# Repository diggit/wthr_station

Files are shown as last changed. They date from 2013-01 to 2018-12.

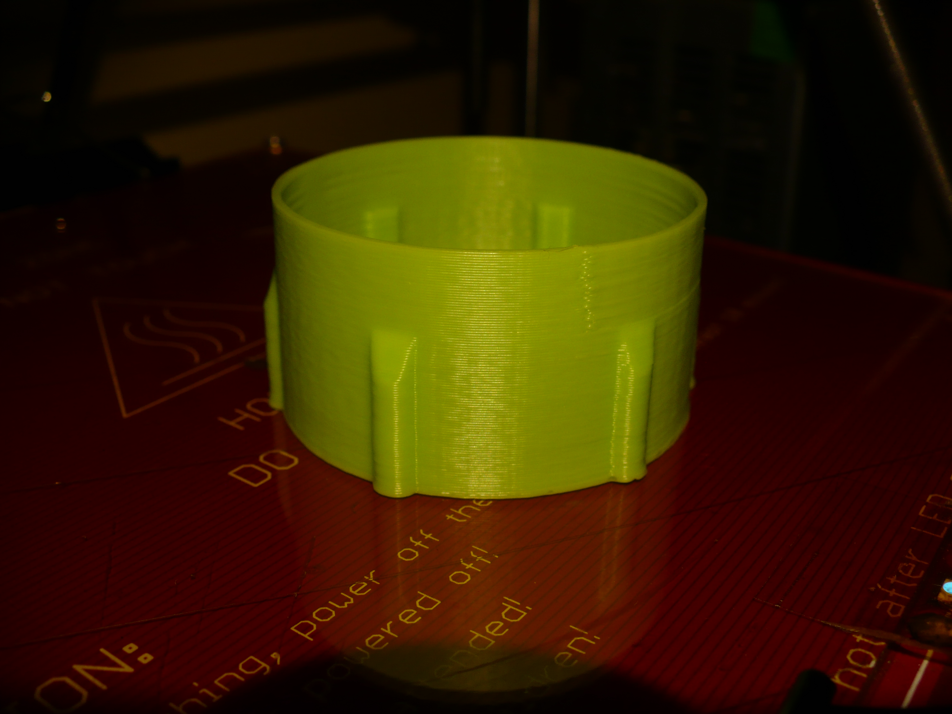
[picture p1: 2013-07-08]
web_app/photo/img3.jpg

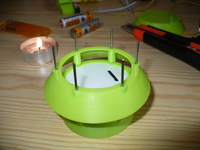
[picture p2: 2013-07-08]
web_app/photo/thumb/img4.jpg

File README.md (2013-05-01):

#Weather station#
============

Final project on secondary school, meteorological/weather station with web access.

## Divided into two main parts:
* Sensors with MCU outside, collecting various values. Newly extended by temperature sensor board (3 ICs). 
* Software running on RaspberryPi, grabs values from sensor "module",
    stores them in mysql database and publishes them on web.

## Material here :

* In **multi_sens** directory are complete sources for sensor module with libraries
  can be build with avr-gcc (tested on (arch)linux with 4.8.0).

* In **root** is python script. Periodicaly executed by cron (every 1O mins and 1min). After execution sends request to sensor
  module (serial communication). Returned structured string is decoded into mesured values. Then script stores values
  into mysql database for further usage and requests some last values. From returned values is generated javascript file
  containing array fileled with values. (used by web page)
  Data from minute updates are used for webpage header only. The are not stored for further usage.

* In **web_app** is web application's root, so index.html and value file(s) generated by script described above are here.
  Design itself is not cool or awesome but works as it should.

* In **electonics** are schematics, PSB designs, their exports for printing, etc.

* In **designs** are models of housing for sensor module now, openscad source and stls of individual parts.
  STLs may be out of date. Use openscad to get up to date design of housing.

* In **photo** are photos of station and it's parts. It really exists!

## STATUS
* working, needs webpage design improvement
* look at: http://m72.dkm.cz or http://meteo-chodov.tk
* ~~Temperature measurements from BMP085 are quite accurate.~~ Sometimes happen, that sensor returs 0°C instead of real value. I was unable to fix it up.
* Extension board with 3 temperature sensors ADT7410 16bit i2c ICs is working. BMP085 reports higher temperature, 1.5°C (approx) above new sensor's value. 
* my 3D printer is not functional now, but I prepared top housing part for new light sensor. This sensor is in queue.

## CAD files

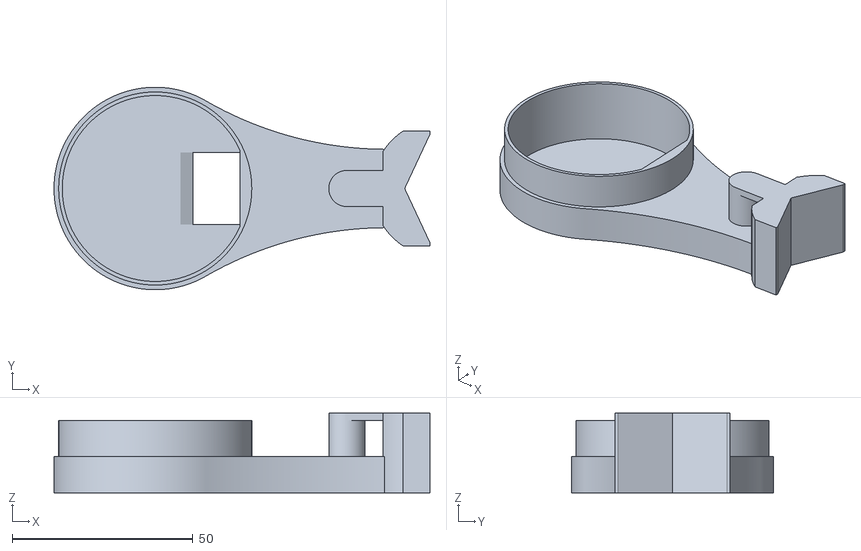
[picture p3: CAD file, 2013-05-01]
designs/sensor_module_housing_rodmount.stl
104.0 x 56.0 x 22.0

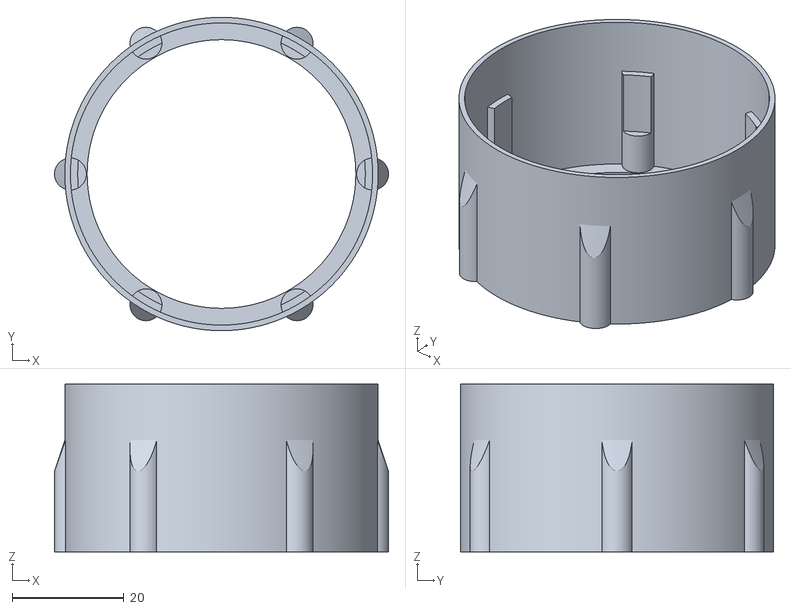
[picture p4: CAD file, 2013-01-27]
designs/sensor_module_housing_bottom.stl
59.7 x 56.0 x 30.0

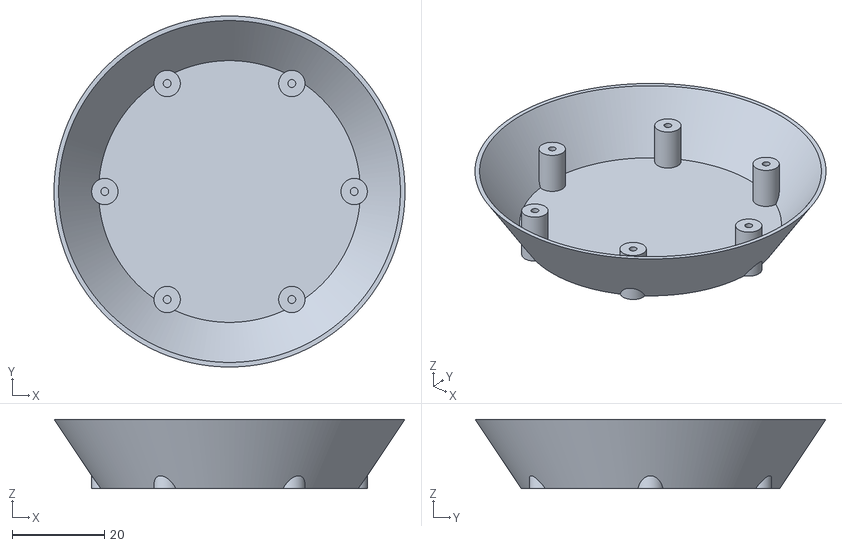
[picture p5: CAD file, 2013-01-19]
designs/sensor_module_housing_top.stl
76.0 x 76.0 x 15.0

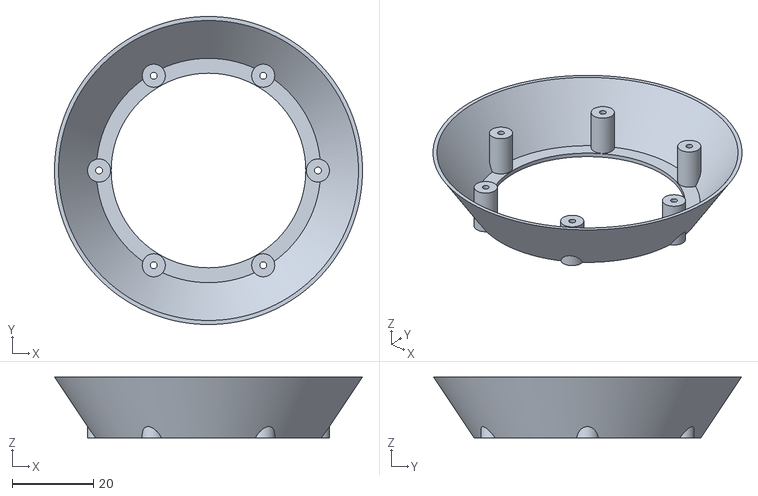
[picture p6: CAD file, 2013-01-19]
designs/sensor_module_housing_middle.stl
76.0 x 76.0 x 15.0

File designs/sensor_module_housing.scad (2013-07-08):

//$fn=200;
$fa=0.5;
$fs=0.1;
T_dia_in=54;
T_thickness=1;
T_height=30;

R_dia_in=T_dia_in;
R_thickness=1;
R_dia_increase=10;
R_height=15;
R_count=3;
R_overlap=4;
R_base=4;

C_count=6;
C_dia_in=1.7;
C_thickness=2;

render=0; //1 bottom, 2 middle (1 floor), 3 top, 4 rod mount,5 top W/ window, 0 all

E_dia=51.4;
E_height=8.5;

M_in_height=10;
M_in_thickness=1;
M_gap=0.3;
M_height=10;
M_cutoff_dia=200;
M_cutoff_angle=30;

if(render==1){
	rotate(a=[180,0,0]){base();}
}
else if(render==2){
	rotate(a=[180,0,0]){rings(1,0);}
}
else if(render==3){
	rotate(a=[180,0,0]){
		rings(1,0);
		top_plate(R_height-1.5);
	}
}
else if(render==4)
{
	rod_mount(10);
}
else if(render==5)
{
	rotate(a=[180,0,0]){
	rings(1,0);
	difference(){
		top_plate(R_height-1.5);
		translate([-5,-5,10])cube([10,10,10]);
		//translate([-10,-10,R_height-0.6])cube([20,20,1]);
		}
	translate([9,-5,R_height-3-1.5])
		difference(){
			cylinder(r=3,h=3);
			cylinder(r=1.3,h=3);
		}
	translate([9,5,R_height-3-1.5])
		difference(){
			cylinder(r=3,h=3);
			cylinder(r=1.3,h=3);
		}
	
		
	}
	
}
else {
	rings(R_count,T_height-R_overlap);
	top_plate(T_height+R_count*(R_height-R_overlap)-1,0);
	base();
	rod_mount(0);
}




module base(){
	difference(){
		union(){
			difference(){//main tubeBH1750FVI
					cylinder(r=T_dia_in/2+T_thickness,h=T_height);
					cylinder(r=T_dia_in/2,h=T_height);
			}

			difference()
			{
				for(i=[0:1:C_count-1]){//columns
					rotate(a=[0,0,i*(360/C_count)]){
						translate(v=[T_dia_in/2,0,10]){
								cylinder(r=C_dia_in/2+C_thickness,h=T_height-10);
						}
					}
				}
				translate(v=[0,0,T_height-15-E_height]){
					cylinder(r=E_dia/2,h=15);
				}
				translate(v=[0,0,10])
				{
					difference(){
						cylinder(h=15,r=T_dia_in/2+T_thickness+5);
						cylinder(h=15,r1=T_dia_in/2+T_thickness,r2=T_dia_in/2+T_thickness+5);
					}
				}
			}
			
			
			translate(v=[0,0,T_height-1]){//ring for safe printing
				difference(){
					cylinder(h=1,r=T_dia_in/2+R_thickness);
					cylinder(h=1,r=T_dia_in/2+R_thickness-R_base);
				}
			}
		}
		for(i=[0:1:C_count-1]){
			rotate(a=[0,0,i*(360/C_count)]){
				translate(v=[T_dia_in/2,0,T_height-10+1]){
						cylinder(r=C_dia_in/2,h=R_height);
				}
			}
		}
		
	}
}


module rings(count,height_offset){
	translate(v=[0,0,height_offset]){
		for(i=[0:1:count-1]){
			translate(v=[0,0,(R_height-R_overlap)*i]){
				difference(){
					union(){//union of ring and columns
						difference(){
							cylinder(h=R_height,r2=R_dia_in/2+R_thickness,r1=R_dia_increase+R_dia_in/2+R_thickness);
							cylinder(h=R_height,r2=R_dia_in/2,r1=R_dia_increase+R_dia_in/2);
						}
						translate(v=[0,0,R_height-1]){//ring for safe printing
							difference(){
								cylinder(h=1,r=R_dia_in/2+R_thickness);
								cylinder(h=1,r=R_dia_in/2+R_thickness-R_base);
							}
						}
						for(i=[0:1:C_count-1]){//columns
							rotate(a=[0,0,i*(360/C_count)]){
								translate(v=[T_dia_in/2,0,R_overlap]){
										cylinder(r=C_dia_in/2+C_thickness,h=R_height-R_overlap);
								}
							}
						}
					}//cut holes in columns
					for(i=[0:1:C_count-1]){
						rotate(a=[0,0,i*(360/C_count)]){
							translate(v=[T_dia_in/2,0,R_overlap]){
									cylinder(r=C_dia_in/2,h=R_height-R_overlap);
							}
						}
					}
				}
			}
		}
	}
}

module top_plate(height_offset){
	translate(v=[0,0,height_offset]){
		cylinder(h=1.5,r2=R_dia_in/2+R_thickness,r1=R_dia_in/2+2*R_thickness);
		for(i=[0:1:C_count-1]){//columns
			rotate(a=[0,0,i*(360/C_count)]){
				translate(v=[T_dia_in/2,0,0]){
						cylinder(r=C_dia_in/2+C_thickness,h=1.5);
				}
			}
		}
	}
}

module rod_mount(height_offset)
{
	color("aqua"){
		translate(v=[0,0,height_offset])
		{
			difference()
			{
				cylinder(h=M_in_height,r=T_dia_in/2-M_gap);
				cylinder(h=M_in_height+1,r=T_dia_in/2-M_gap-M_in_thickness);
			}
			difference()
			{
				translate(v=[0,0,-10])
				{
					difference()
					{
						cylinder(h=M_height,r=T_dia_in/2+T_thickness);
						translate(v=[0,0,2]){cylinder(h=M_height-2,r=T_dia_in/2-M_gap-M_in_thickness);}
					}
					difference()
					{
						translate(v=[0,-T_dia_in/2,0]){cube([cos(90-M_cutoff_angle)*(T_dia_in/2+T_thickness+M_cutoff_dia/2),T_dia_in,M_height]);}
						for(i=[0,1])
						mirror([0,i,0])
						{	
							rotate([0,0,-M_cutoff_angle])
							{
								translate(v=[-20,0,0]){cube([20,70,M_height]);}
								translate(v=[0,T_dia_in/2+T_thickness+M_cutoff_dia/2,0])
								{
								
									cylinder(h=M_height,r=M_cutoff_dia/2);
								
								}
							}
						}
						cylinder(h=M_in_height+1,r=T_dia_in/2-M_gap-M_in_thickness);
						//translate(v=[cos(90-M_cutoff_angle)*(T_dia_in/2+T_thickness+M_cutoff_dia/2),-T_dia_in/2,0])
						//{//the end of mount
						//	cube([100,T_dia_in,M_height]);
							
						//}
					}
					translate(v=[cos(90-M_cutoff_angle)*(T_dia_in/2+T_thickness+M_cutoff_dia/2)-1,0,0])
					{//the end of mount
						difference()
						{
							union()
							{
								difference()
								{
									for(i=[0,1]) mirror([0,i,0]) {cube([13,5+sin(90-M_cutoff_angle)*(T_dia_in/2+T_thickness+M_cutoff_dia/2)-M_cutoff_dia/2,M_height*2+2]);}
									translate(v=[16,0,0])
									{
										difference()
										{	
											cylinder(h=22,r=30);	
											cylinder(h=22,r=19);	
										}
									}
								}
								translate(v=[-10,0,10])
								{
									cylinder(h=12,r=5);
								}
								translate(v=[-10,-5,20])
								{
									cube([15,10,2]);
								}
							}
							translate(v=[6,0,0])
								for(i=[20,-20])
								mirror([0,i,0])
								rotate([0,0,-45+i])
								{
									cube([17,17,30]);
								}
						}
			
						
					}
					//because rounded bridges are problem...
					intersection()
					{
						translate(v=[T_dia_in/2-3.5,-21,0])
						{
							cube([10,40,20]);
						}
						cylinder(h=20,r=T_dia_in/2-M_gap);
					}
				}
				translate([0,-10,-4])
				{
					rotate([0,30,0])
					{
						cube([60,20,15]);
					}
				}
				
			}
			%translate(v=[-10,0,-1])//connectors, main and wind(combined speed and dir)
			{
				translate(v=[-5,10,-8])
				{
					RJ4pMount();
				}
				translate(v=[0,-11,-8])//RJ45 mount for wind sensors
				{
					difference()
					{
						translate(v=[0,-10,1]){cube([15,20,5]);}
						#translate(v=[0,-7,1]){cube([15,15.8,5]);}
					}
				}
			}

		}
		
		
	}
	
	
}

module RJ4p()
{
	color("red"){
		translate(v=[3,-11.8/2,0])
		{
			cube([17,11.8,15]);
			
		}
		translate(v=[15.5,-14.5/2,0])
		{
			cube([1.5,14.5,15]);
		}
	}
}

module RJ4pMount()
{
	difference()
	{
		translate(v=[5,-10,1]){cube([15,20,5]);}
		RJ4p();
	}
}

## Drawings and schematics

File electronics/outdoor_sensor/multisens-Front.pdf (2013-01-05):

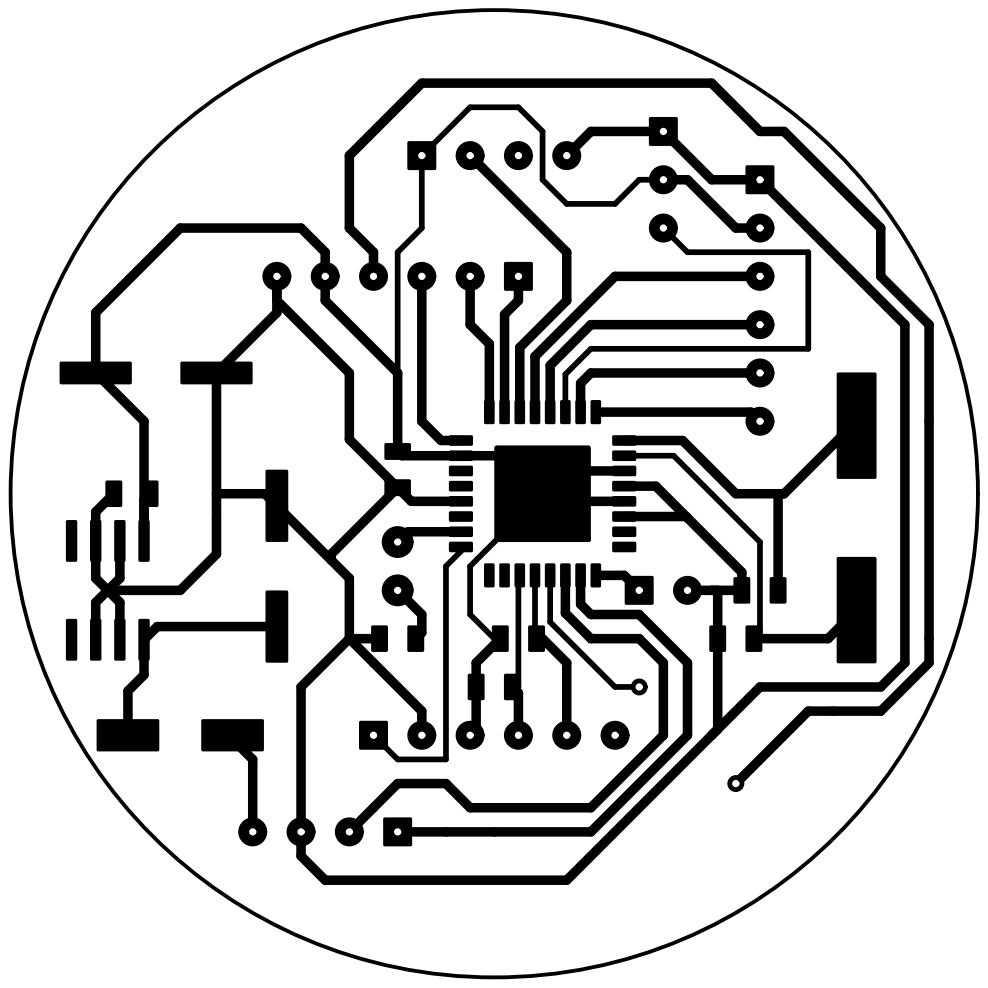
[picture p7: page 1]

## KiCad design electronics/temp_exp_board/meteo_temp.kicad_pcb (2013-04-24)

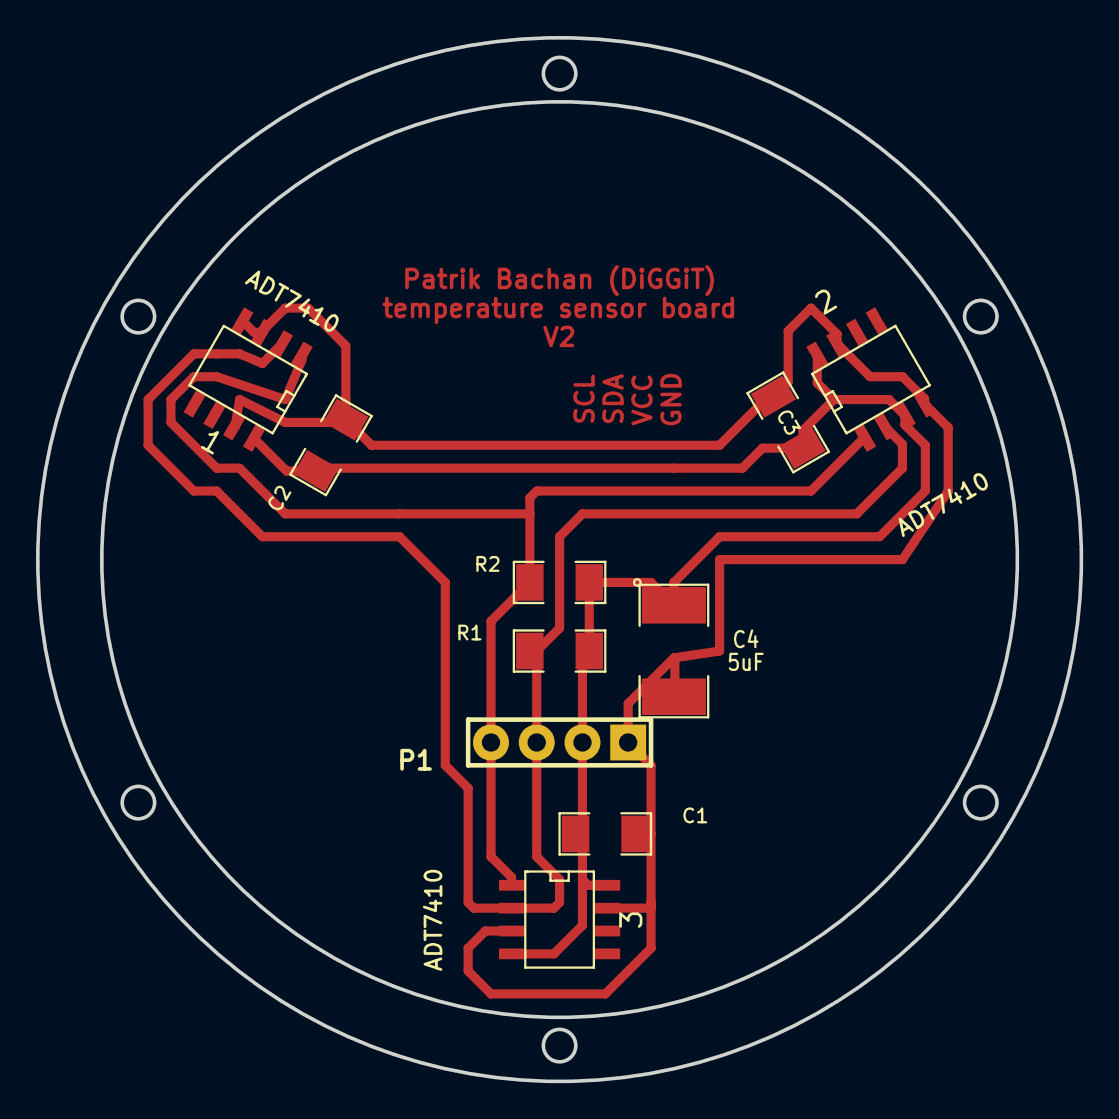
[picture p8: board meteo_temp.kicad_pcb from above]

Board: 2 copper layers, 58.0 x 58.0 mm, 10 parts (0 on the bottom side), 4 nets.

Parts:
1, 2, 3: ADT7410; SO8E
C1, C2, C3: 100n; SM1206
C4: 5uF; SM1812L
P1: MAIN; PIN_ARRAY_4x1
R1, R2: 5k; SM1206

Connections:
unnamed: 1.1, 2.1, 3.1, P1.4, R2.2
unnamed: 1.2, 2.2, 3.2, P1.3, R1.2
unnamed: 1.8, 2.3, 2.8, 3.4, 3.8, C1.1, C2.1, C3.1, C4.1, P1.2, R1.1, R2.1
unnamed: 1.3, 1.4, 1.7, 2.4, 2.7, 3.3, 3.7, C1.2, C2.2, C3.2, C4.2, P1.1

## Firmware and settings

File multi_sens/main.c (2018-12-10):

/***************************************************************************
 * Desc: Program for controller Atmega8, it will be placed near sensors,
 * reads raw values, converts them and on masters request, sends them back over UART
 * USED sensors are: temperature and pressure digital i2c sensor BMP085
 * humidity digital sensor DHT11
 * 
 * Author: Patrik Bachan
 * Contact:patrikbachan@gmail.com (email), diggit@jabbim.cz (jabber)
 * 
 * License: GNU GPL v3
 ***************************************************************************/
#include <avr/io.h>
#include <avr/interrupt.h>
#include <avr/sleep.h>

#include "i2cmaster.h"
#include "uart.h"//useful UART functions, init, send, receive and so on
#include "calibrated_loop.h"
#include "misc.h"
#include "config.h"
#include "dht.h"
#include "ADT.h"//library for extended temperature board
#include "BMP.h" 
#include "BH1750.h" 

#define LED_CFG() DDRC|=1
#define LED_ON() PORTC|=1
#define LED_OFF() PORTC &=~1


//TODO: move to header file
void handleERROR(uint8_t ERROR_code);

uint8_t hw_check()
{
	#ifdef debug
	uart_println("HW check...");
	uart_print("i2c ");
	#endif

	if(i2c_check())
	{
		error_flags.i2c=1;
		#ifdef debug
			uart_println("FAIL, skipping all i2c sensors!");
		#endif
	}
	else
	{
		error_flags.i2c=0;
		#ifdef debug
		uart_println("OK");
		#endif
	}

	if(error_flags.i2c==0)
	{


		#ifdef debug
			uart_print("BMP085 ");
		#endif
		if(BMP_check())
		{
			#ifdef debug
				uart_println("FAIL");
			#endif
			error_flags.BMP=1;
		}
		#ifdef debug
			else
				uart_println("OK");
		#endif



		if(ADT_check())
		{
			#ifdef debug
			uart_print("ADT fail, sns: ");
			for(int i=0;i<ADT_sensor_count;i++)
			{
				if(ADT_status&(1<<i))
				{
					uart_num(i,1);
					uart_putc(',');
				}

			}
			uart_println(" unresponsive");
			#endif
			error_flags.ADT=1;
		}
		#ifdef debug
		else
			uart_println("ADT OK");
		#endif
		ADT_shutdown();//put sensors into shutdown mode (low self heating)
	}

	

	#ifdef debug
		uart_print("DHT ");
	#endif
	if(DHT(DHT_sensor_pin))
	{
		error_flags.DHT=1;
		#ifdef debug
			uart_println("FAIL");
		#endif
	}
	#ifdef debug
	else
		uart_println("OK");
	#endif


	#ifdef debug
		uart_println("hw check DONE!");
	#endif
	return 0;
}

int main (void)
{
	DDRB=0;
	DDRD=0;
	DDRC=0;
	LED_CFG();
	LED_ON();
	uart_init();//init UART
	uart_print("booted...\ncompiled: ");
	uart_println(STRING_VERSION);
	i2c_init();//bring up I2C

	hw_check();
	

	if(error_flags.i2c==0 && error_flags.BMP==0)
	{
		//bmp init()
		BMP_get_calibration();//download callibration values from BMP085
		BMP_read_temperature();//initial reading
		BMP_read_pressure();//same here	
	}
	
	set_sleep_mode(SLEEP_MODE_IDLE); //choose most suitable sleep mode - IDLE (still running UART)
	sleep_enable();//enable sleeping
	
	
	sei(); //enable interrupt, mainly for UART RX

	#ifdef debug
	uart_println("entering infinite sleep loop...");
	#endif
	while(1)//sleep it after interrupt again and again
	{
		LED_OFF();
		#ifdef debug
		uart_println("sleeping");//debug
		#endif
		sleep_enable();
		sleep_cpu();//MCU is awaken on every interrupt, this will sleep it back again...
	}	
	
	return 0;
}



ISR(USART_RXC_vect)//return measured values on request, otherwivise, node will be in idle mode, (maybe sleeping - should be implemented)
{
	LED_ON();
	#ifdef debug
		uart_println("woken");
	#endif
	cli();

	char reply=UDR; //latch incomming data byte
	
	//BMP085 output
	int16_t bmp_temperature=0;
	uint32_t bmp_pressure=0;
	//ADT7410 output
	int16_t adt_temperature=0;
	//DHT humidity
	uint8_t dht_humidity=0;
	//BH light
	uint16_t bh_light=0;


	if(reply=='Q')//send data as response of Query
	{
		uart_println("measuring...");
		hw_check();

		if(error_flags.i2c || BH_measure())//get value from EX board
			error_flags.BH=1;
		else
			error_flags.BH=0;

		if(error_flags.i2c || BMP_measure(&bmp_pressure,&bmp_temperature))
		{
			error_flags.BMP=1;
			bmp_pressure=0;
			bmp_temperature=0;
		}
		else
			error_flags.BMP=0;

		if(error_flags.i2c || ADT_measure(&adt_temperature,ADT_samples,ADT_pause))//get value from EX board
		{
			error_flags.ADT=1;
			adt_temperature=0;
		}
		else
			error_flags.ADT=0;

		if(DHT(DHT_sensor_pin))
		{
			error_flags.DHT=1;	
			dht_humidity=0;
		}
		else
		{
			error_flags.DHT=0;	
			dht_humidity=DHT_response[0];
		}

		if(error_flags.i2c || error_flags.BH || BH_read(&bh_light))//get value from EX board
			error_flags.BH=1;
		
		if(error_flags.BH)
			bh_light=0;
		




//ADT------------------------------------------		
		//power on sensors on EXT board
		
		
		uart_print("!,MULTISNS1,T0,");//some ID
		uart_num((int32_t)adt_temperature,3);//temp from ex
		
		uart_print(",T1,");
		uart_num(bmp_temperature,1);//bmp_temperature from BMP085
		
		uart_print(",P0,");//bmp_pressure from BMP085
		uart_num(bmp_pressure,1);

		uart_print(",H0,");//himudity from DHT11
		uart_num(dht_humidity,1);

		uart_print(",L0,");//light intensity from BH1750
		uart_num(bh_light,1);

		//errors
		uart_print(",GEN,");
		uart_num(error_flags.general,1);

		uart_print(",I2C,");
		uart_num(error_flags.i2c,1);

		uart_print(",ADT,");
		uart_num(error_flags.ADT,1);

		//each sensor status
		for (int i = 0; i < ADT_sensor_count; ++i)
		{
			uart_print(",ADT");
			uart_num(i,1);
			uart_putc(',');
			uart_num( (ADT_status&(1<<i)) ? 1 : 0,1);	
		}
		
		uart_print(",BMP,");
		uart_num(error_flags.BMP,1);

		uart_print(",DHT,");
		uart_num(error_flags.DHT,1);

		uart_print(",BHL,");
		uart_num(error_flags.BH,1);

		uart_print(",$\n");
		
	}
	else if (reply=='R')
	{
		uart_println("Resetting...");
		Reset_AVR();
	}
	else uart_println("send Q to get data or R for reset");
	
	#ifdef debug
		uart_println("ERR dump: ");
		uart_print("GEN:");
		uart_num(error_flags.general,2);
		uart_nl();

		uart_print("i2c:");
		uart_num(error_flags.i2c,2);
		uart_nl();

		uart_print("ADT:");
		uart_num(error_flags.ADT,2);
		uart_nl();

		uart_print("BMP:");
		uart_num(error_flags.BMP,2);
		uart_nl();
	#endif

	delay_us(500000);//DHT needs some refresh, just for case of too often reading
	uart_flush();/*something weird, if Q was incomming without pause, interrupt occured one by one. 
	* No MCU sleep was done. 24th reading from sensors returned wrong values and next would block MCU. 
	* Solution was total MCU Reset (see above). So, multiple requests (too short pause between them) are ignored for now...*/
	sei();
}

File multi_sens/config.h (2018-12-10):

// Copyright (C) 2014  xorly

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

//main configuration

#ifndef _CONFIG
	#define _CONFIG
	#include <avr/io.h>

	//#define debug

	#define STRING_VERSION __DATE__ " " __TIME__ // build date and time

	#define FOSC 16000000UL //MCU crystal freq.
	#define F_CPU FOSC
	//UART-config--------------------------------------------------------------------------------------------------------------------------------
	#define BAUD 19200UL //speed of UART, for short distances could be increased, bud don't forget to change value in grabber script on server...
	#define UART_RX_INT //enable UART recieve INT
	#define UART_RX
	#define UART_TX

	//DHT11-config--------------------------------------------------------------------------------------------------------------------------------
	#define DHTP PORTB //PORT where DHT11 data pin is attached
	#define DHTD DDRB  //...it's configuration register (I/O selection)
	#define DHTI PINB  //register where to get actual status of input
	#define DHT_sensor_pin 2
	#define DHT_retry_count 5
	
	//I2C-config--------------------------------------------------------------------------------------------------------------------------------
	#define I2C_CLOCK  100000L
	
	//ADT-config--------------------------------------------------------------------------------------------------------------------------------	
	#define ADT_sensor_count 3
	#define ADT_minimum_working 3
	#define ADT_addr_base 0b01001000 //aligned to left
	#define ADT_samples 5
	#define ADT_pause	500 //ms

	//BMP085-config-------------------------------------------------------------------------------------------------------------------------------
	//addresses of BMP085 i2c sensor
	#define BMP_ADDR 0b01110111
	
	//resolution of BMP085 pressure measurement
	#define BMP_resolution 3 //0 fastest - worst, 3 slowest - best
	#define BMP_max_pressure_noise 10 //pressure treshold
	#define BMP_max_temperature_noise 5 //temperature treshold
	#define BMP_samples 3 //samples count which value shouldn't be too far from it's avg. value eg AVG:200 val1:201 val2:198 val3:203 -worst distance is 3 (=|200-203|), values above are tresholds 
	#define BMP_max_tries 5 //if measured values were too far from their AVG value, try it until OK or max_tries is reached
	#define BMP_int_reg PINC
	#define BMP_int_pin	1
	#define BMP_pause 50 //millisecond pause between samples
	//BMP085-config-------------------------------------------------------------------------------------------------------------------------------

	//BH1750-config-------------------------------------------------------------------------------------------------------------------------------
	#define BH1750_ADDR	0b00100011
	//BH1750-config-------------------------------------------------------------------------------------------------------------------------------

#endif

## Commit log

2012-12-05 sign overflow fix, extended display functions
    [main.c]
2012-12-06 pressure read appended, val. differs from real, need fix
    [main.c]
2012-12-08 UART output migration
2012-12-08 DHT11 support added, some code fixes
    [main.c]
2012-12-08 uart functions moved away
2013-01-05 PCB design, initial commit
    [multisens.brd, multisens.sch]
2013-01-12 initial design push
    [sensor_module_housing.scad]
2013-01-12 design export
    [sensor_module_housing.scad]
2013-01-12 design output in stl
    [sensor_module_housing_bottom.stl, sensor_module_housing_middle.stl, sensor_module_top.stl]
2013-01-19 design modifications
    [sensor_module_housing.scad, sensor_module_housing_bottom.stl, sensor_module_housing_middle.stl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]
2013-01-27 rod mount finished
    [sensor_module_housing.scad]
2013-01-27 minor fixes
    [sensor_module_housing_bottom.stl]
2013-01-27 arduino BL, correct LED pin, shorter delay
    [ATmegaBOOT.c]
2013-02-03 design update
    [sensor_module_housing.scad]
2013-02-18 error filter
2013-04-24 top part with window
    [sensor_module_housing.scad]
2013-04-24 no changes
    [multisens.brd]
2013-04-24 getting prepared on temp. expansion board
2013-04-24 new expansion board for temp. sensors
    [meteo_temp.kicad_pcb, meteo_temp.sch]
2013-04-24 commented #include of not xet finished expansion board lib
2013-04-25 better comented code, error handling improvement in progress
    [main.c]
2013-05-01 added support for extension temperature board
2013-05-01 initial commit of EXt temp.board library
2013-05-01 part for mounting onto tube, rod,... (vertical)
    [sensor_module_housing_rodmount.stl]
2013-05-02 bugfix, wrong bitewise shift operation (artefact)
    [temp.c]
2013-05-18 switched default rendering opt.
    [sensor_module_housing.scad]
2013-05-18 response error detection and warning on webpage
    [grabber_daemon.py]
2013-06-18 high temperature overflow fix
    [temp.c]
2013-07-08 typo fixed
    [sensor_module_housing.scad]
2014-08-09 sensor checking and skipping
    [ADT.c]
2014-08-09 interrupt enable fix, newline func, macro merged
    [uart.c]
2014-08-10 use status LED
2018-12-10 add light sensor
2018-12-10 fix problems with uart and parsing
    [grabber_daemon.py, main.c]
2018-12-13 fix typo from copy paste
    [grabber_daemon.py]
2018-12-16 more tweaks to plot size, add missing hr
    [grabber_daemon.py]
2018-12-16 add missing hr in index, use tight_layout for plots
    [grabber_daemon.py]

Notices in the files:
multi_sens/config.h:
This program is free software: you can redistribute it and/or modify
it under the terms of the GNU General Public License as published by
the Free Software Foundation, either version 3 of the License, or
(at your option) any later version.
